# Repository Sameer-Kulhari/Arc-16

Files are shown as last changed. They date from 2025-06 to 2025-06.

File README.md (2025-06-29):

# Arc-16

Arc-16 is a macro-pad with 16 keys,oled and rgb for aesthetics and look ,with a custom cool looking 3d case and working on kmk firmware .

## Features :
- 16 keys 
- Oled (128*32)
- Rgb under keys 
- kmk firmware
- 3 layers for rgb and functions control keys

## CAD :
#### Here are some looks of Arc-16 .

It has two parts top and bottom which can be assembled using M3 screws and heatsets.The design is made in Onshape.

### Full Case 

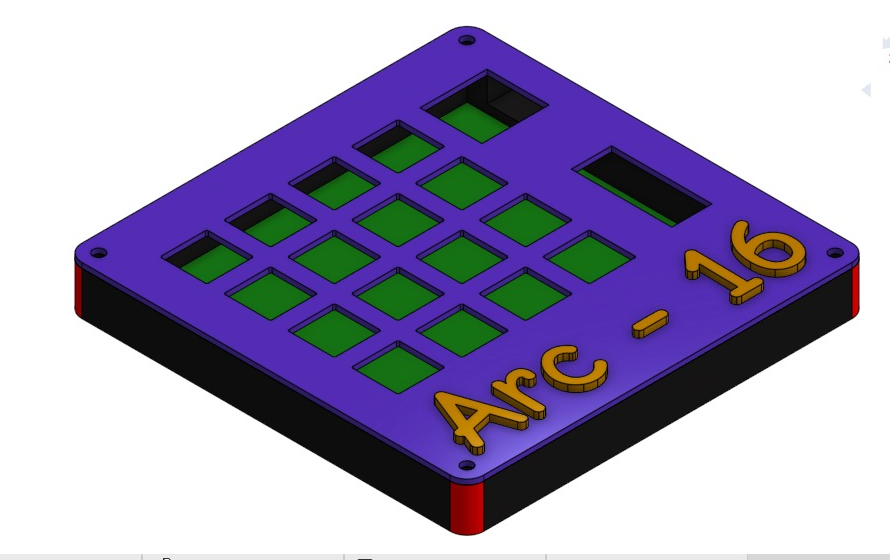
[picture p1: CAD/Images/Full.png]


### Bottom
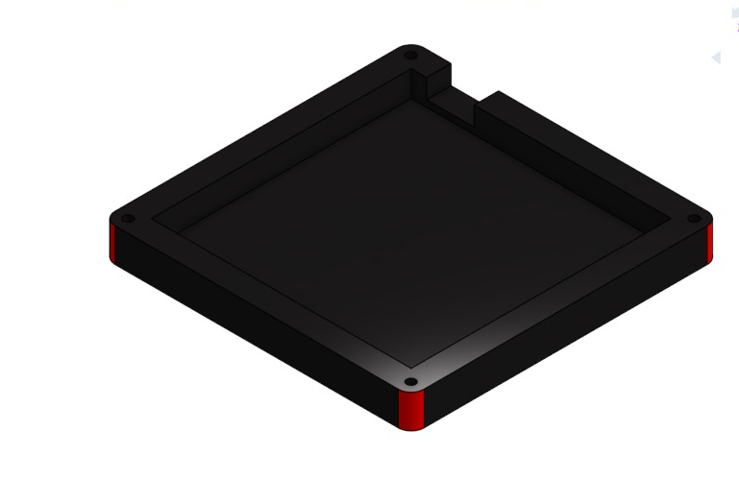
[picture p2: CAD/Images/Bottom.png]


## PCB :
#### Here are some looks of PCB

This pcb is made in kicad.
### 3d view

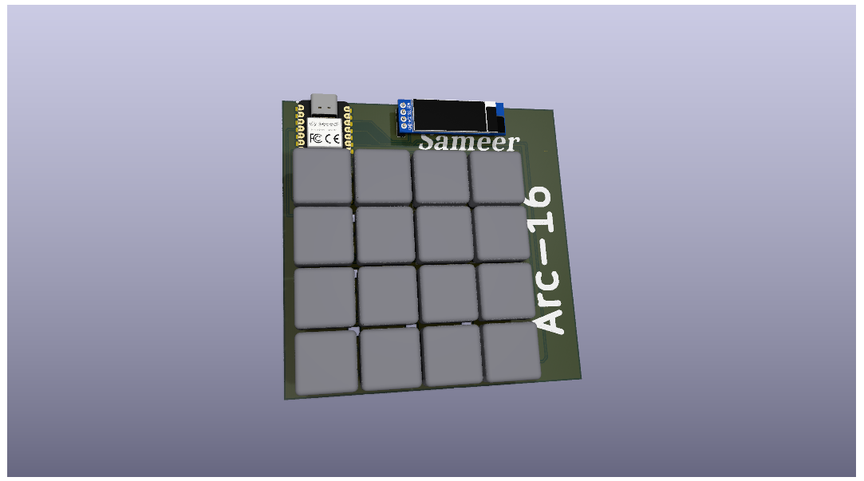
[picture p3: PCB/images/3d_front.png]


### Schematics

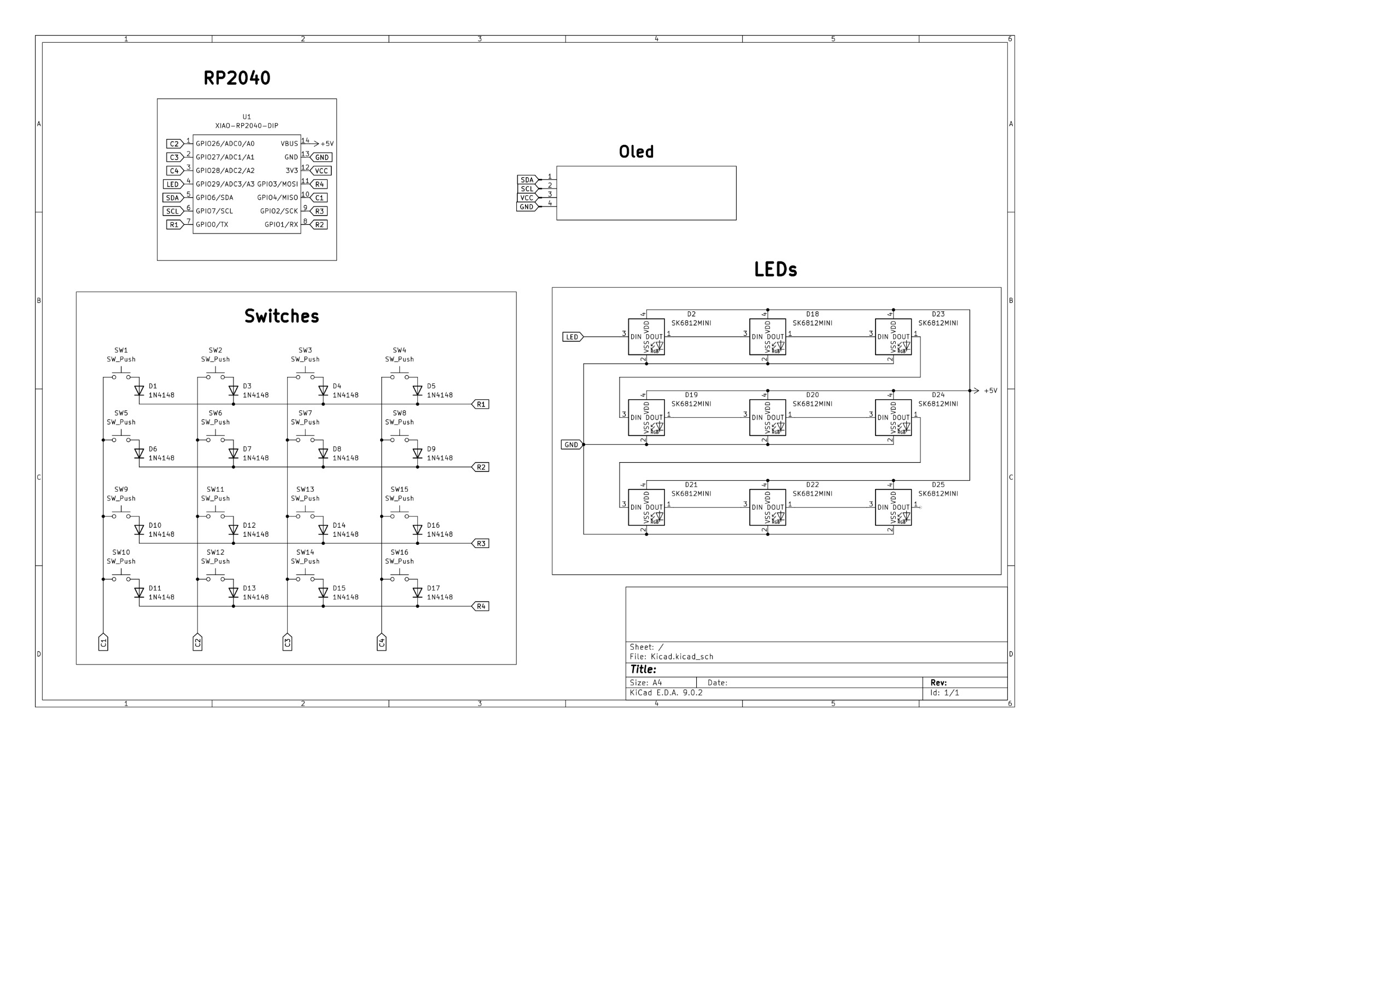
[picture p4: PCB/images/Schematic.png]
Schematic


## Firmware 
### Arc -16 uses kmk Firmware with Circuit-python

- 3 layers for more keys
- Oled displays current layer
- Rgb with different modes

## BOM 
Here is a list of materials required to make the Arc-16

- 1x Seeed XIAO RP2040
- 16x Cherry MX 1.0u Switches
- 1x 0.91 inch OLED display
- 9x SK6812 mini-e LEDs
- 16x 1N14148 diodes
- Pcb of Arc-16
- Case of Arc-16
- 4x M3 screws
- 4x M3 heatsets
- 16x Blank DSA keycaps

## Extra 

### All images are attached in each section along with dependancies.Have a look at it.
####  _________________Thank You!____________________

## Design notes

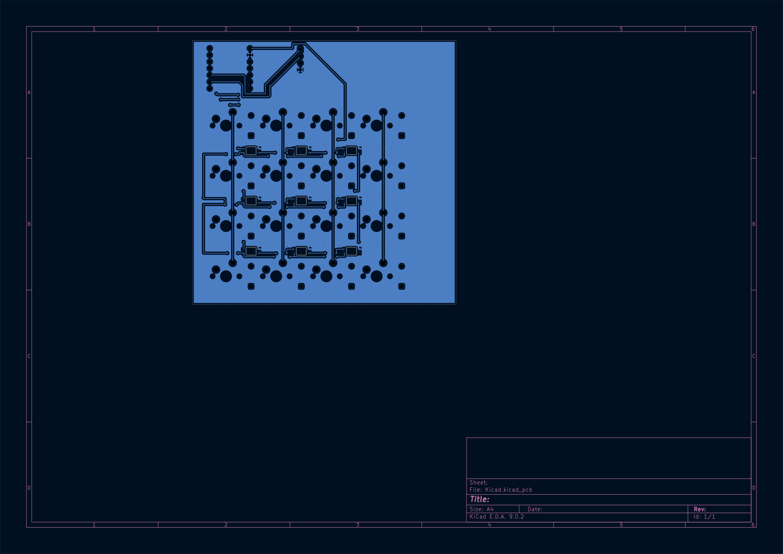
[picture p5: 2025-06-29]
PCB/images/B_Cu.png

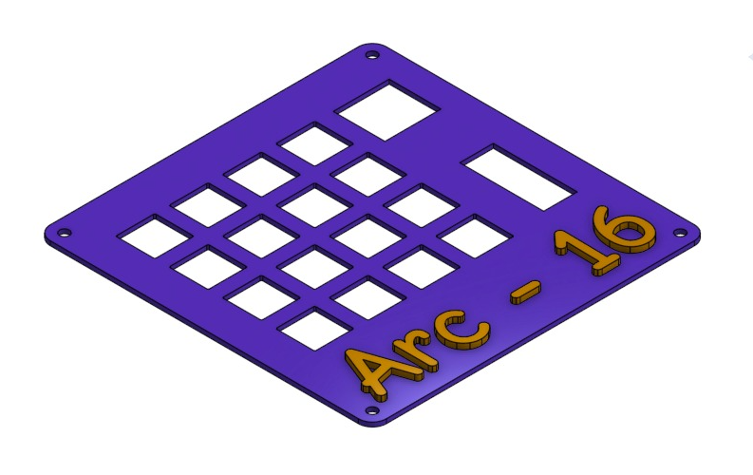
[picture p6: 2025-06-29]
CAD/Images/Top.png

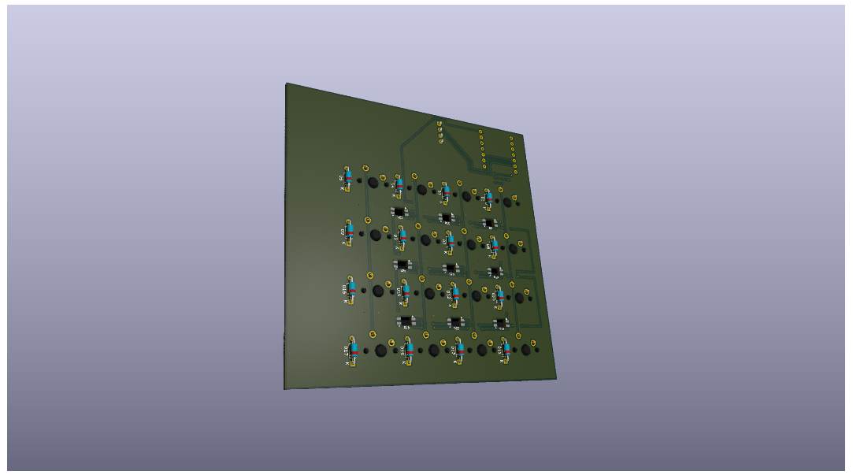
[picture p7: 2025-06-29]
PCB/images/3d_back.png

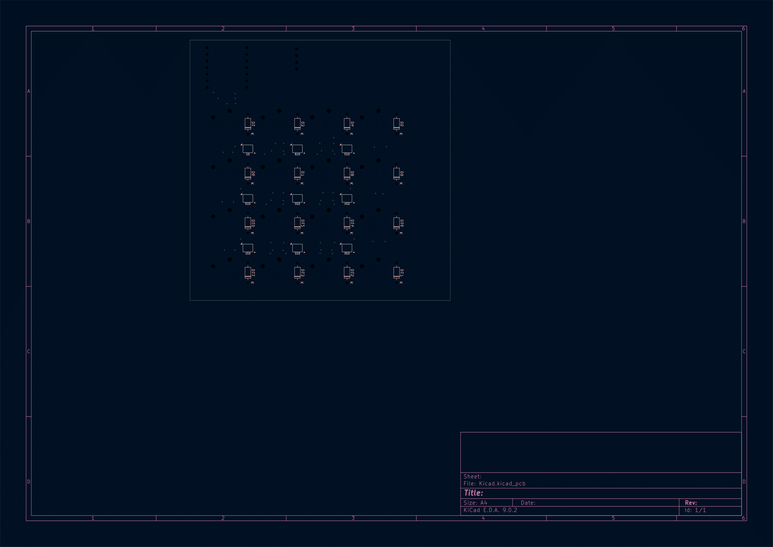
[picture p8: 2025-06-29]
PCB/images/B_Silkscreen.png

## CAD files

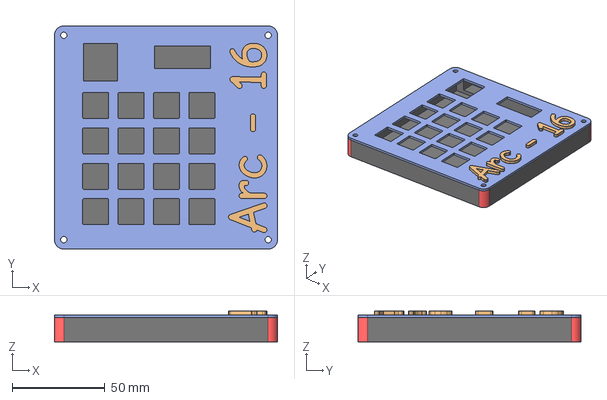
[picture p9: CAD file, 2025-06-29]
CAD/Full_Case_without_pcb.step
120.0 x 120.0 x 16.5 mm

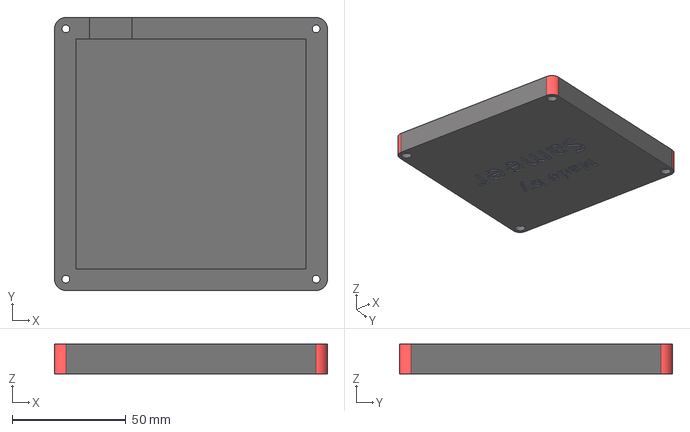
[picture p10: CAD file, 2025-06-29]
Production/Bottom.step
120.0 x 120.0 x 13.0 mm

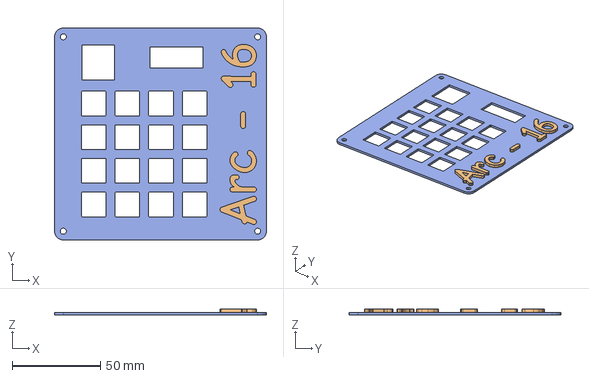
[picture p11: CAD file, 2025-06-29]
Production/Top.step
120.0 x 120.0 x 3.50 mm

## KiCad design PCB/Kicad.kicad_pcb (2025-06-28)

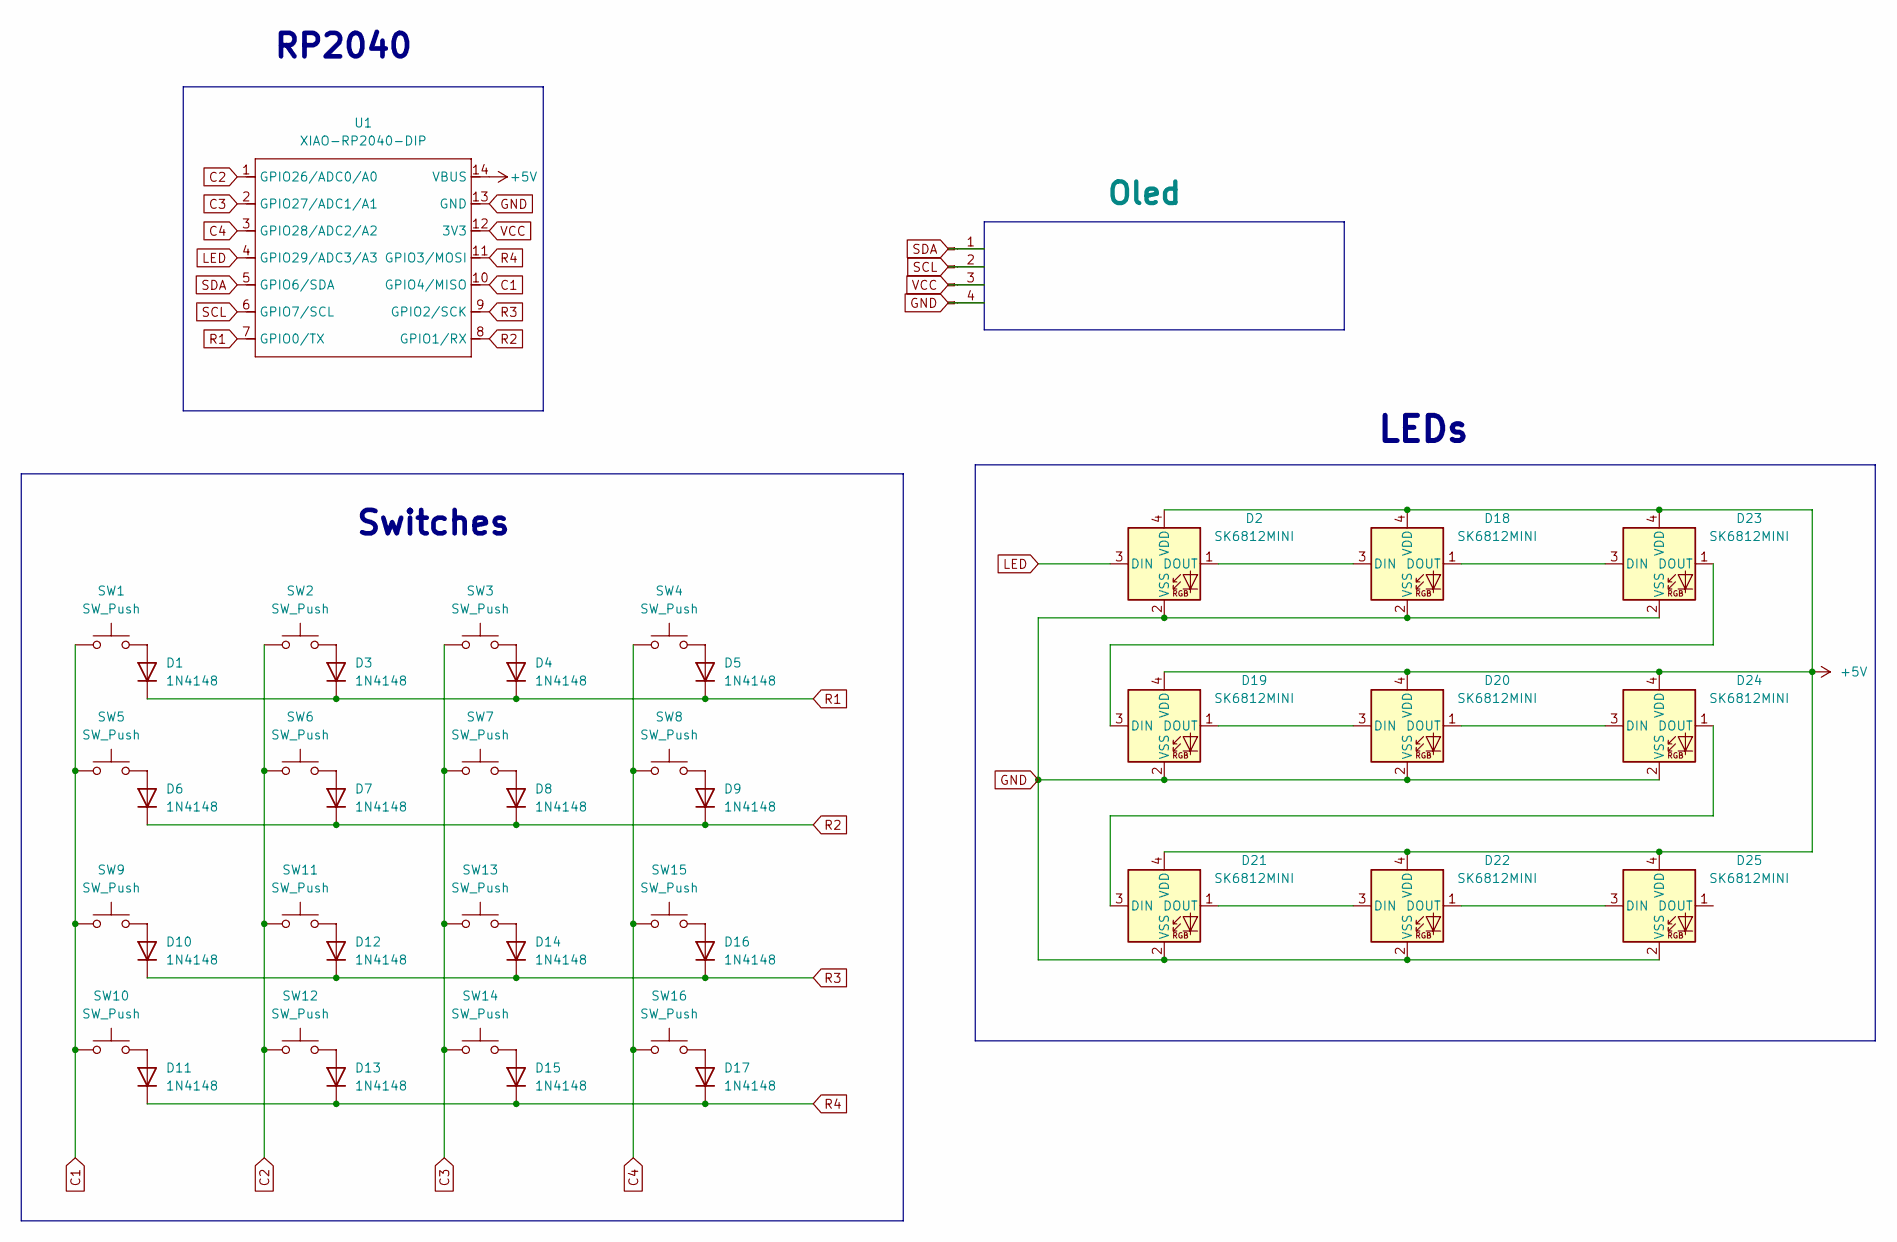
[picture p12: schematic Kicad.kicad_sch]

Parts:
D1, D3, D4, D5, D6, D7, D8, D9, D10, D11, D12, D13, D14, D15, D16, D17: 1N4148; D_DO-35_SOD27_P7.62mm_Horizontal
D2, D18, D19, D20, D21, D22, D23, D24, D25: SK6812MINI; SK6812-MINI-E
J1: Oled; PinHeader_1x04_P2.54mm_Vertical
SW1, SW2, SW3, SW4, SW5, SW6, SW7, SW8, SW9, SW10, SW11, SW12, SW13, SW14, SW15, SW16: SW_Push; SW_Cherry_MX_1.00u_PCB_With_3d
U1: XIAO-RP2040-DIP

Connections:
+5V: D2.4 (VDD), D18.4 (VDD), D19.4 (VDD), D20.4 (VDD), D21.4 (VDD), D22.4 (VDD), D23.4 (VDD), D24.4 (VDD), D25.4 (VDD), U1.14 (VBUS)
C1: SW1.1, SW5.1, SW9.1, SW10.1, U1.10 (GPIO4/MISO)
C2: SW2.1, SW6.1, SW11.1, SW12.1, U1.1 (GPIO26/ADC0/A0)
C3: SW3.1, SW7.1, SW13.1, SW14.1, U1.2 (GPIO27/ADC1/A1)
C4: SW4.1, SW8.1, SW15.1, SW16.1, U1.3 (GPIO28/ADC2/A2)
GND: D2.2 (VSS), D18.2 (VSS), D19.2 (VSS), D20.2 (VSS), D21.2 (VSS), D22.2 (VSS), D23.2 (VSS), D24.2 (VSS), D25.2 (VSS), J1.4, U1.13 (GND)
LED: D2.3 (DIN), U1.4 (GPIO29/ADC3/A3)
unnamed: D1.2 (A), SW1.2
unnamed: D3.2 (A), SW2.2
unnamed: D4.2 (A), SW3.2
unnamed: D5.2 (A), SW4.2
unnamed: D6.2 (A), SW5.2
unnamed: D7.2 (A), SW6.2
unnamed: D8.2 (A), SW7.2
unnamed: D9.2 (A), SW8.2
unnamed: D10.2 (A), SW9.2
unnamed: D11.2 (A), SW10.2
unnamed: D12.2 (A), SW11.2
unnamed: D13.2 (A), SW12.2
unnamed: D14.2 (A), SW13.2
unnamed: D15.2 (A), SW14.2
unnamed: D16.2 (A), SW15.2
unnamed: D17.2 (A), SW16.2
unnamed: D2.1 (DOUT), D18.3 (DIN)
unnamed: D18.1 (DOUT), D23.3 (DIN)
unnamed: D19.3 (DIN), D23.1 (DOUT)
unnamed: D19.1 (DOUT), D20.3 (DIN)
unnamed: D20.1 (DOUT), D24.3 (DIN)
unnamed: D21.3 (DIN), D24.1 (DOUT)
unnamed: D21.1 (DOUT), D22.3 (DIN)
unnamed: D22.1 (DOUT), D25.3 (DIN)
R1: D1.1 (K), D3.1 (K), D4.1 (K), D5.1 (K), U1.7 (GPIO0/TX)
R2: D6.1 (K), D7.1 (K), D8.1 (K), D9.1 (K), U1.8 (GPIO1/RX)
R3: D10.1 (K), D12.1 (K), D14.1 (K), D16.1 (K), U1.9 (GPIO2/SCK)
R4: D11.1 (K), D13.1 (K), D15.1 (K), D17.1 (K), U1.11 (GPIO3/MOSI)
SCL: J1.2, U1.6 (GPIO7/SCL)
SDA: J1.1, U1.5 (GPIO6/SDA)
VCC: J1.3, U1.12 (3V3)

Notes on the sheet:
LEDs
Switches
RP2040

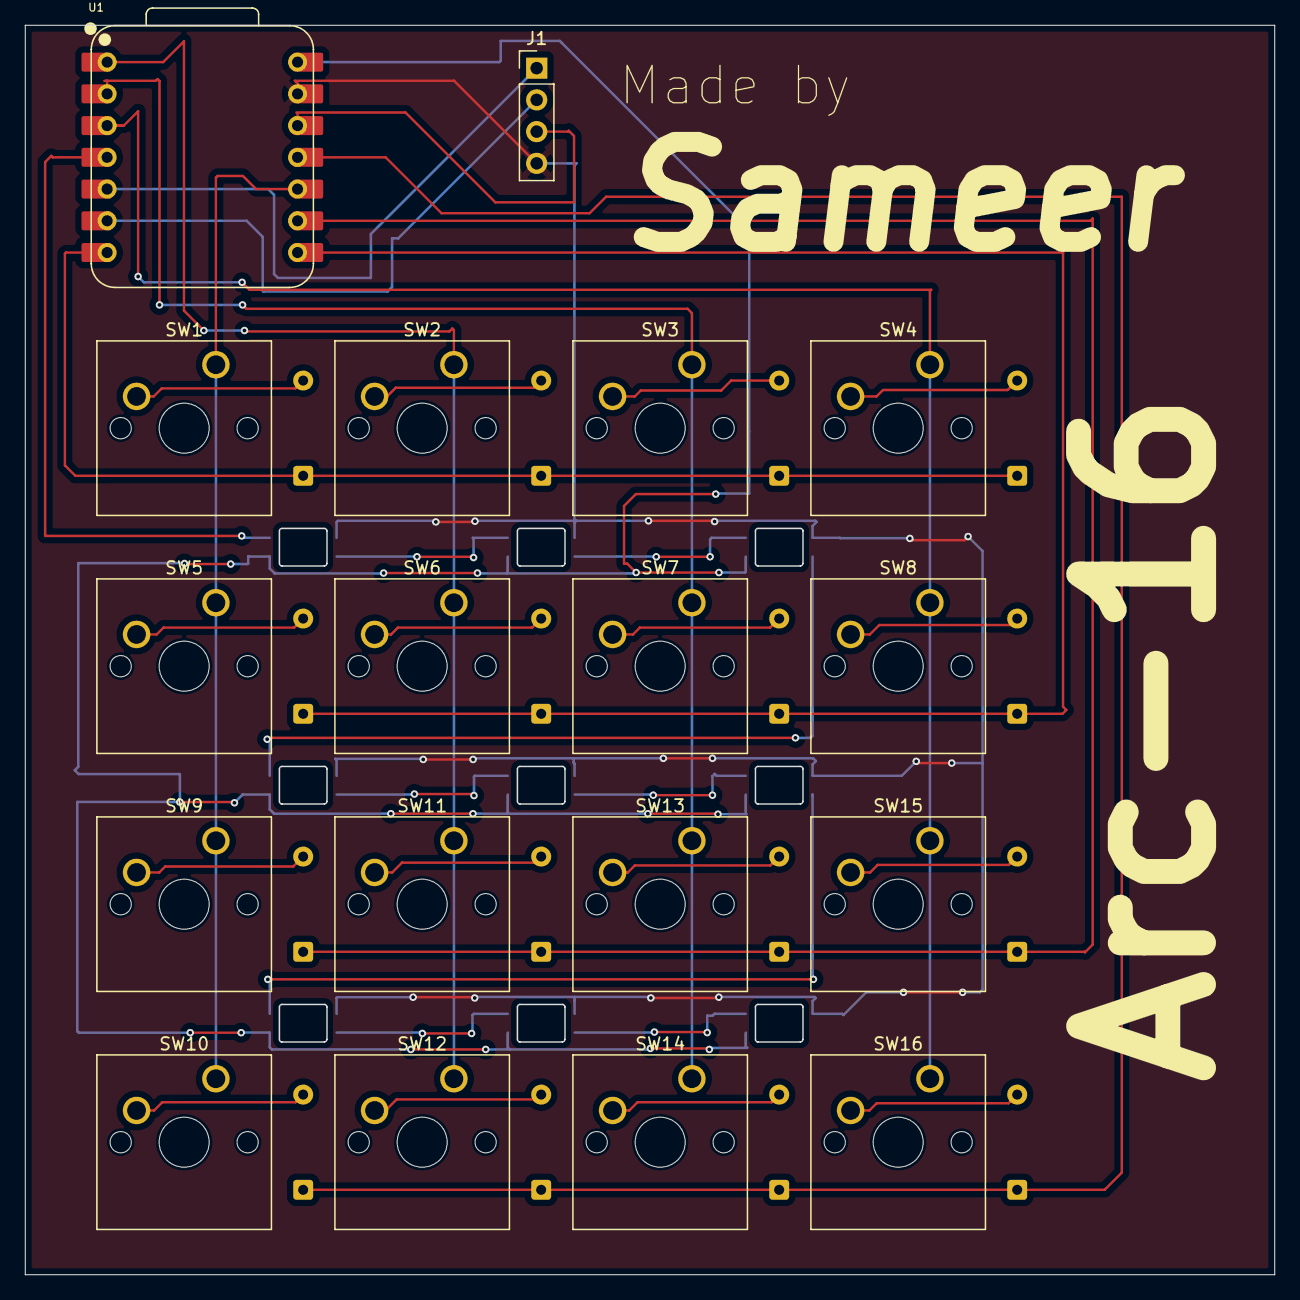
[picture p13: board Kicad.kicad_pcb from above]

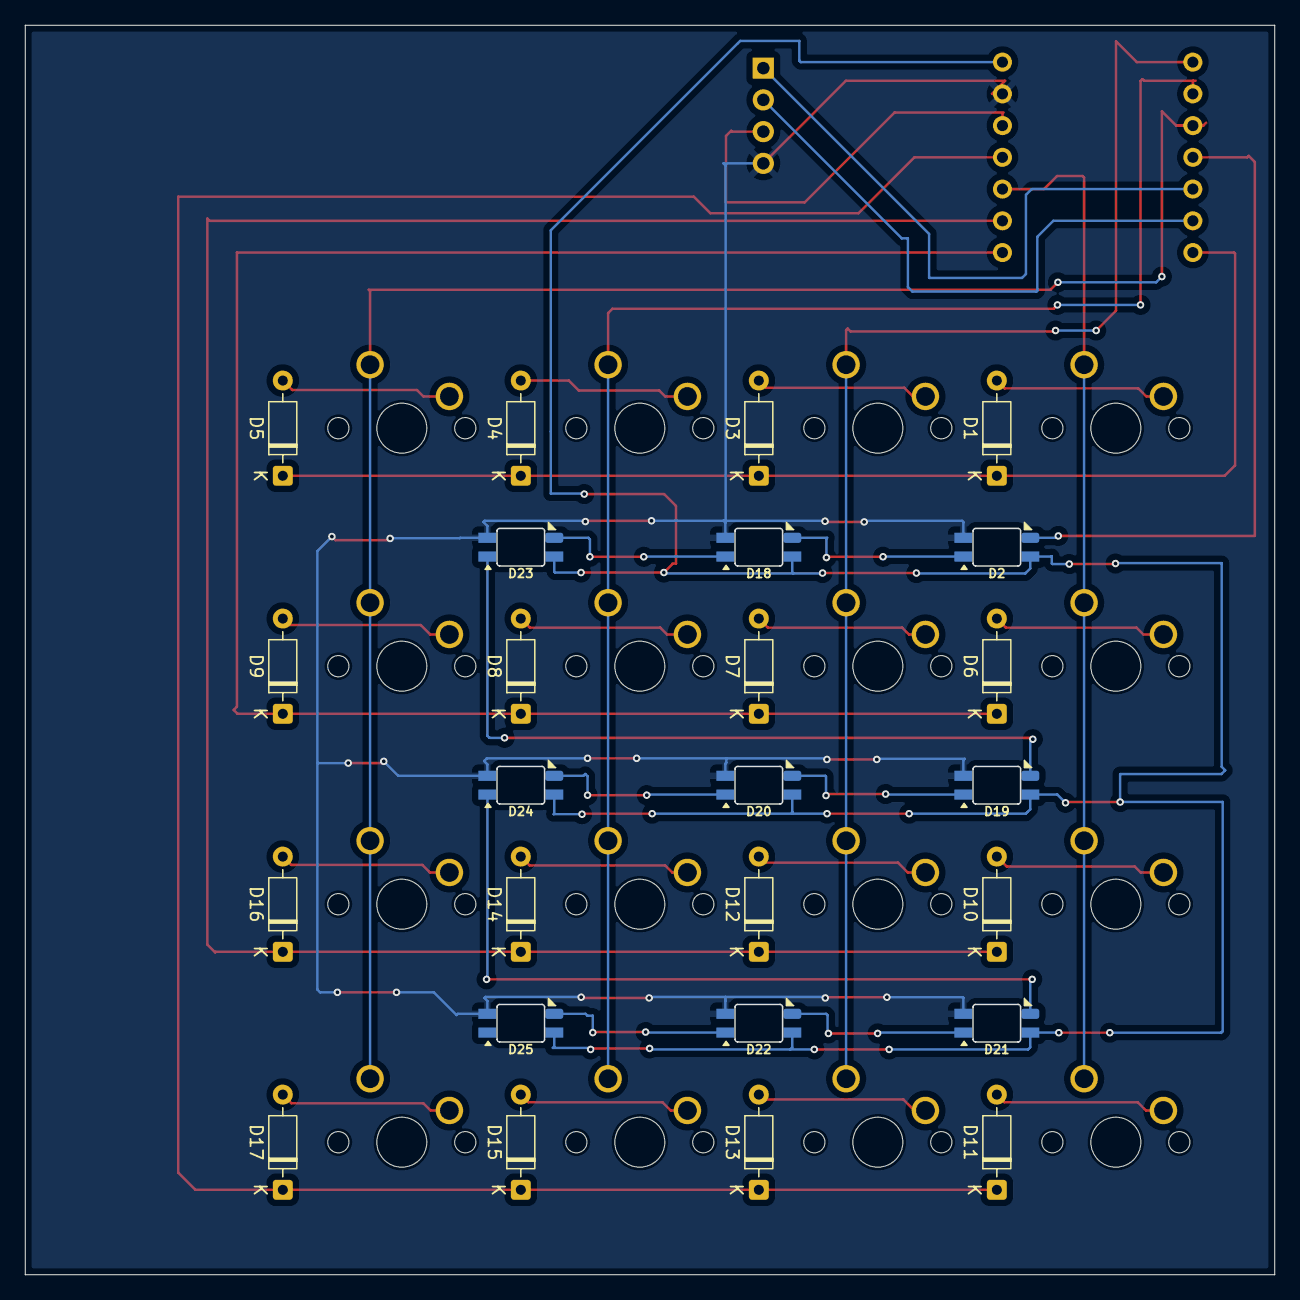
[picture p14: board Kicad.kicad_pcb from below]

Board: 2 copper layers, 100.0 x 100.0 mm, 43 parts (25 on the bottom side), 38 nets.

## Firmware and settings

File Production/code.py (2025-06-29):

import board
from kmk.kmk_keyboard import KMKKeyboard
from kmk.scanners import MatrixScanner
from kmk.keys import KC
from kmk.modules.layers import Layers
from kmk.modules.rgb import RGB 
from kmk.extensions.display import Display
from kmk.extensions.display.display_oled import DisplayOLED 
from adafruit_display_text.label import Label
import terminalio


keyboard = KMKKeyboard()


keyboard.col_pins = (board.GPIO4, board.GPIO26, board.GPIO27, board.GPIO28)
keyboard.row_pins = (board.GPIO0, board.GPIO1, board.GPIO2, board.GPIO3)
keyboard.diode_orientation = MatrixScanner.DIODE_COL2ROW


keyboard.modules.append(Layers())


rgb = RGB(
    pixel_pin=board.GPIO29,
    num_pixels=9,
    rgb_order=(1, 0, 2),  # GRB
    brightness_limit=64,
    animation_speed=2.0,
)
rgb.default_rgb_effect = rgb.RGB_MODE_BREATHE_RAINBOW
keyboard.modules.append(rgb)


oled = DisplayOLED(
    width=128,
    height=32,
    sda=board.SDA,
    scl=board.SCL,
    addr=0x3C,
    rotate=0,
)
display = Display(oled)

# OLED for showing current layer name
def draw_oled(display_inst, keyboard):
    current_layer = keyboard.active_layers[0] if keyboard.active_layers else 0
    layer_names = ['Base', 'Fn', 'RGB']
    name = layer_names[current_layer] if current_layer < len(layer_names) else f'Layer {current_layer}'

    display_inst.clear_display_group()
    label = Label(terminalio.FONT, text=f'Layer: {name}', x=0, y=8)
    display_inst.display_group.append(label)

display.draw_callback = draw_oled
keyboard.extensions.append(display)



LAYER_FN = KC.TG(1)   
LAYER_RGB = KC.TG(2)  
LAYER_BASE = KC.TG(0) 

# Keymap
keyboard.keymap = [

    # Layer 0: Base
    [
        KC.ESC,  KC.Q,    KC.W,    KC.E,
        KC.A,    KC.S,    KC.D,    KC.F,
        KC.Z,    KC.X,    KC.C,    KC.V,
        LAYER_FN, KC.SPC, KC.ENT,  KC.BSPC,
    ],

    # Layer 1: Function Layer
    [
        KC.TILD, KC.N1,   KC.N2,   KC.N3,
        KC.N4,   KC.N5,   KC.N6,   KC.N7,
        KC.N8,   KC.N9,   KC.N0,   KC.MINS,
        LAYER_RGB, KC.LEFT, KC.DOWN, KC.RIGHT,
    ],

    # Layer 2: RGB Controls
    [
        KC.RGB_TOG, KC.RGB_MOD, KC.RGB_HUI, KC.RGB_HUD,
        KC.RGB_VAI, KC.RGB_VAD, KC.NO,      KC.NO,
        KC.NO,      KC.NO,      KC.NO,      KC.NO,
        LAYER_BASE,    KC.TRNS,    KC.TRNS,    KC.TRNS,
    ]
]

if __name__ == '__main__':
    keyboard.go()

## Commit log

2025-06-28 Added Kicad files
    [Kicad.kicad_pcb, Kicad.kicad_sch]
2025-06-28 Added footprint for project
2025-06-29 Plate Design added
2025-06-29 Added CAD files
    [Bottom.step, Full_Case_without_pcb.step, Top.step]
2025-06-29 Added new files
    [Bottom.step, Top.step]
